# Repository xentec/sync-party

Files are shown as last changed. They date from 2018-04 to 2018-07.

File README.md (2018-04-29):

## Sync-Party

Synchrongesteurte RC-Autos.

### Kompileren

Zum Kompilieren des Projektes reicht es die `build.sh` auszuführen. Die fertigen Binaries liegen direkt im `bin`-Ordner.

### Settings

**Pololu Motor Controller**

The Pololu Motor Controller recieves a PWM signal via the RC1 pin from the arduino. If the PWM signal was generated with the following compare values (in register ORC2A) on the arduino the motor will speed up to the direction
	0x10 means full reverse speed
	0x30 means stop the motor
	0x90 means full forward speed

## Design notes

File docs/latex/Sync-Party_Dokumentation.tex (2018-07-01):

\RequirePackage{silence} % :-\
    \WarningFilter{scrreprt}{Usage of package `titlesec'}
    %\WarningFilter{scrreprt}{Activating an ugly workaround}
    \WarningFilter{titlesec}{Non standard sectioning command detected}
\documentclass[titlepage,paper=a4paper,fontsize=11pt, ngerman]{scrreprt}
\usepackage[left=2.5cm,right=2.5cm,top=2cm,bottom=2cm,includehead,includefoot]{geometry}

%********************************************************************
% Note: Make all your adjustments in here
%*******************************************************
\input{classicthesis-config}
% ********************************************************************
% GO!GO!GO! MOVE IT!
%*******************************************************
\begin{document}
\frenchspacing
\raggedbottom
\selectlanguage{ngerman} % american ngerman
%********************************************************************
% Frontmatter
%*******************************************************
\include{Gestaltung/Titlepage}
\include{Gestaltung/Contents}
%********************************************************************
% Mainmatter
%*******************************************************
\cleardoublepage
\pagestyle{scrheadings}
\pagenumbering{arabic}
\cleardoublepage
%\include{Kapitel/Einfuehrung}
\include{Anhang/Anhang}
\include{Anhang/literatur}
\end{document}
% ********************************************************************

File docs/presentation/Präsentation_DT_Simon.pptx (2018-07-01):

## Bitte beachten!

Auf den folgenden Seiten finden Sie Tipps zur Anwendung

## µController

- Hardware

  - Raspberry Pi 3 Model B
  - Arduino Uno Rev 3
  - Pololu Simple High-Power Motor Controller 18v15

## µController

- Hardware

  - Raspberry Pi 3 Model B
  - Arduino Uno Rev 3
  - Pololu Simple High-Power Motor Controller 18v15

## Controller

- Hardware

  - Playstation DUALSHOCK4 Wireless Controller

## Sensoren

- Hardware

  - Parallax INF PING))) Ultrasonic Distance Sensor
  - Logitech Webcam C300

## Aktuatoren

- Hardware

  - Modelcraft 4519 Servo
  - Brushed DC Motor (Chassis)

## Akkus

- Hardware

  - Power Bank
  - Nickel-Metall-Hybrid Akku

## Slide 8

- Pololu Motor Controller 18v15

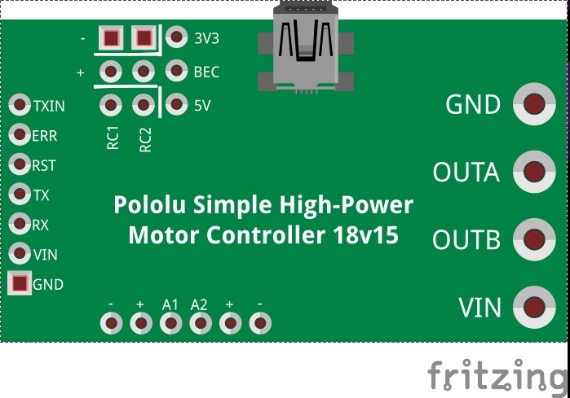
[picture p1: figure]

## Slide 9

- Pololu Motor Controller 18v15

- Kalibrierung: (RC1 Kanal)
Motor Stop: High Anteil 18.75%

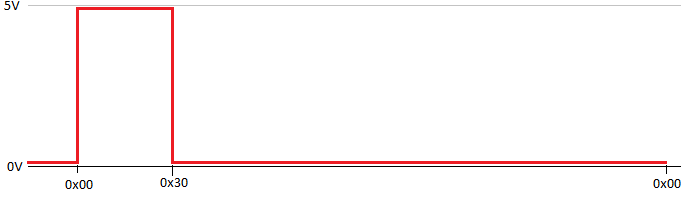
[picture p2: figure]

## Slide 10

- Pololu Motor Controller 18v15

- Kalibrierung: (RC1 Kanal)
Motor Full Forwards: High Anteil ~100%

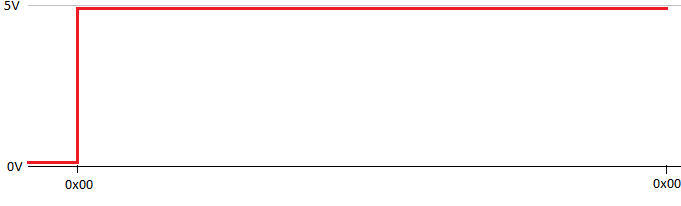
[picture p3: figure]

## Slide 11

- Pololu Motor Controller 18v15

- Kalibrierung: (RC1 Kanal)
Motor Full Backwards: High Anteil 6,25%

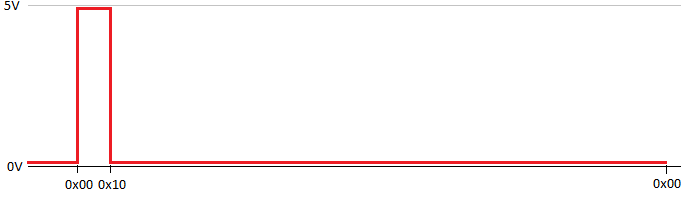
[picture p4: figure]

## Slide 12

- Modelcraft 4519 Servo

- Periodenlänge 2 ms

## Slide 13

- Parallax INF PING))) Ultrasonic Distance Sensor

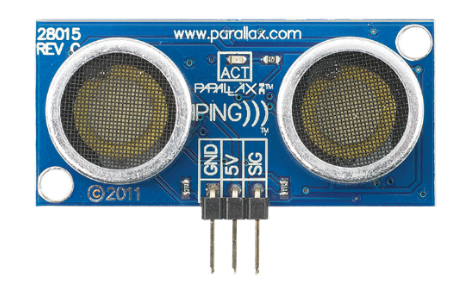
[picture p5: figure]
Ein Bild, das Tennis, Elektronik, Schläger enthält. Mit sehr hoher Zuverlässigkeit generierte Beschreibung
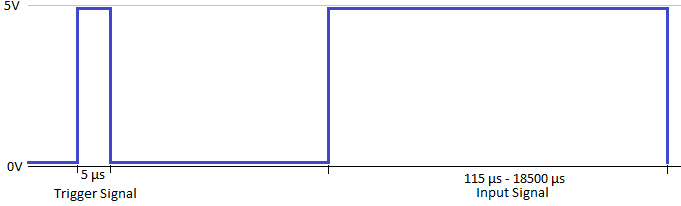
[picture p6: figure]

## Aufgaben

- Arduino Uno Rev 3

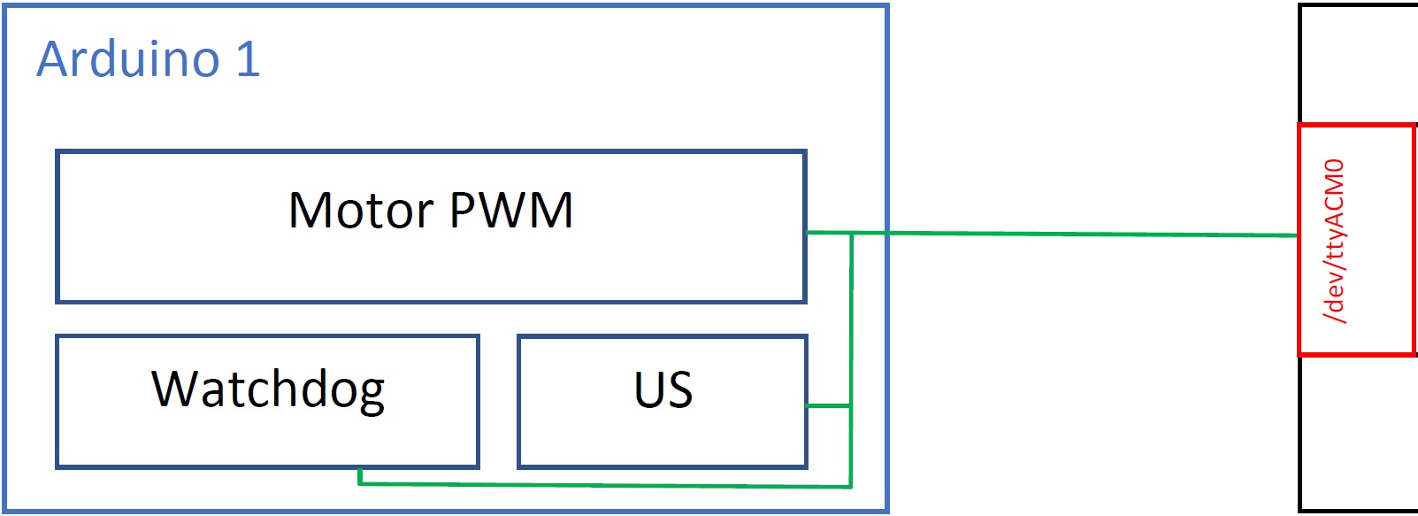
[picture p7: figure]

## PWM Signal

- Arduino Uno Rev 3

  - Ausgabe am Pin 11
  - Periodenlänge: 4 ms
  - Timer 2, FastPWM, Clear Pin 11 on Compare Match
  - Setzen der Compare Werte durch den Compare Interrupt

## Ultraschall

- Arduino Uno Rev 3

  - Ausgabe/Eingabe am Pin 7
  - Erzeugung des Trigger Signals
  - Messen des Input Signals
  - Umrechnung der Zeit in Distanz

## Watchdog

- Arduino Uno Rev 3

  - Überprüfen, ob das Programm auf den Raspberry Pi noch läuft
  - Periodisches Senden von Nachrichten über die serielle Schnittstelle
  - Warten bis Antwort kommt
  - Bei fehlender Antwort innerhalb 200 ms, Motor auf Stop schalten

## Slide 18

- Playstation DUALSHOCK4 Wireless Controller

- Verbindung über Bluetooth mit Master Raspberry Pi
- Steuerung der Geschwindigkeit über R2 (vorwärts) und L2 (rückwärts)
- Steuerung der Fahrtrichtung über den linken Joystick

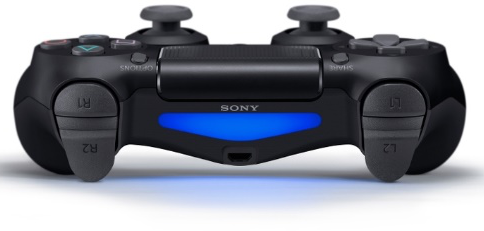
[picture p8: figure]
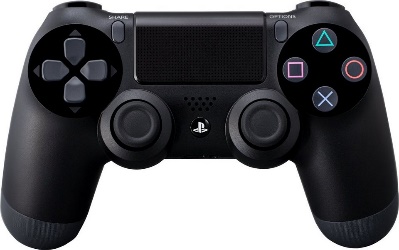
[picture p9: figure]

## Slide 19

- Schematischer Aufbau

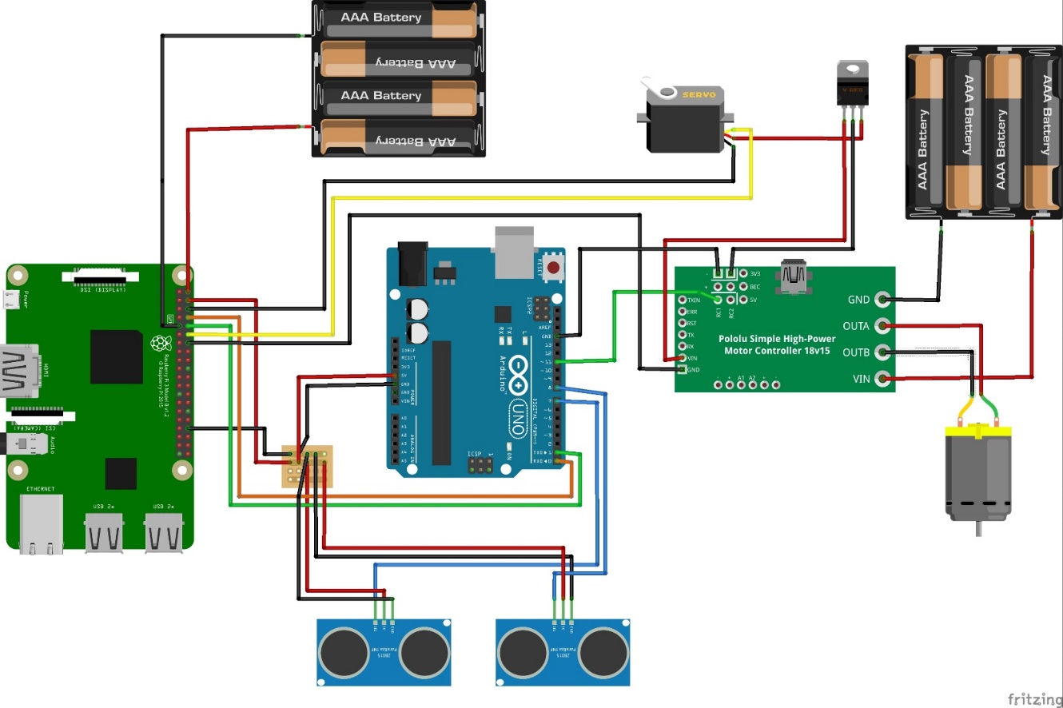
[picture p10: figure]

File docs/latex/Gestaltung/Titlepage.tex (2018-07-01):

%*******************************************************
%Gestaltung der Titelseite
%*******************************************************
\begin{titlepage}
	% if you want the titlepage to be centered, uncomment and fine-tune the line below (KOMA classes environment)
	
	\vspace{1cm}
	\begin{center}       
        \spacedallcaps{\small{\myUni}} \\
        \spacedallcaps{\small{\myFaculty}} \\ \vspace*{2\baselineskip}
		\Large     
        \begingroup
        	\spacedallcaps{\textbf{\myTitle}} \\ \vspace*{2\baselineskip}
            \textbf{\mySubtitle}
        \endgroup
        \large
        \vspace*{10\baselineskip}
		\begin{table}[h]
			\centering
			\begin{tabularx}{0.5\textwidth}{|X|X|}
			\hline 
			\textbf{Name} & \textbf{Matrikelnummer} \\
			\hline 
			Eichenseer, Johannes & 3106172 \\ 
			\hline 
			Hölzl, Simon & 3047424 \\ 
			\hline 
			Leher, Adrian & 3049303 \\ 
			\hline 
			Tran, Luu Ngoc & 3032963 \\ 
			\hline 
			Utz, Andrej & 3012095 \\ 
			\hline
			\end{tabularx}
		\end{table}
    	\begin{figure}[b]
    		\begin{center}
		    	\myTime, \myLocation
	    	\end{center}
    	\end{figure}
    \end{center}
\end{titlepage}

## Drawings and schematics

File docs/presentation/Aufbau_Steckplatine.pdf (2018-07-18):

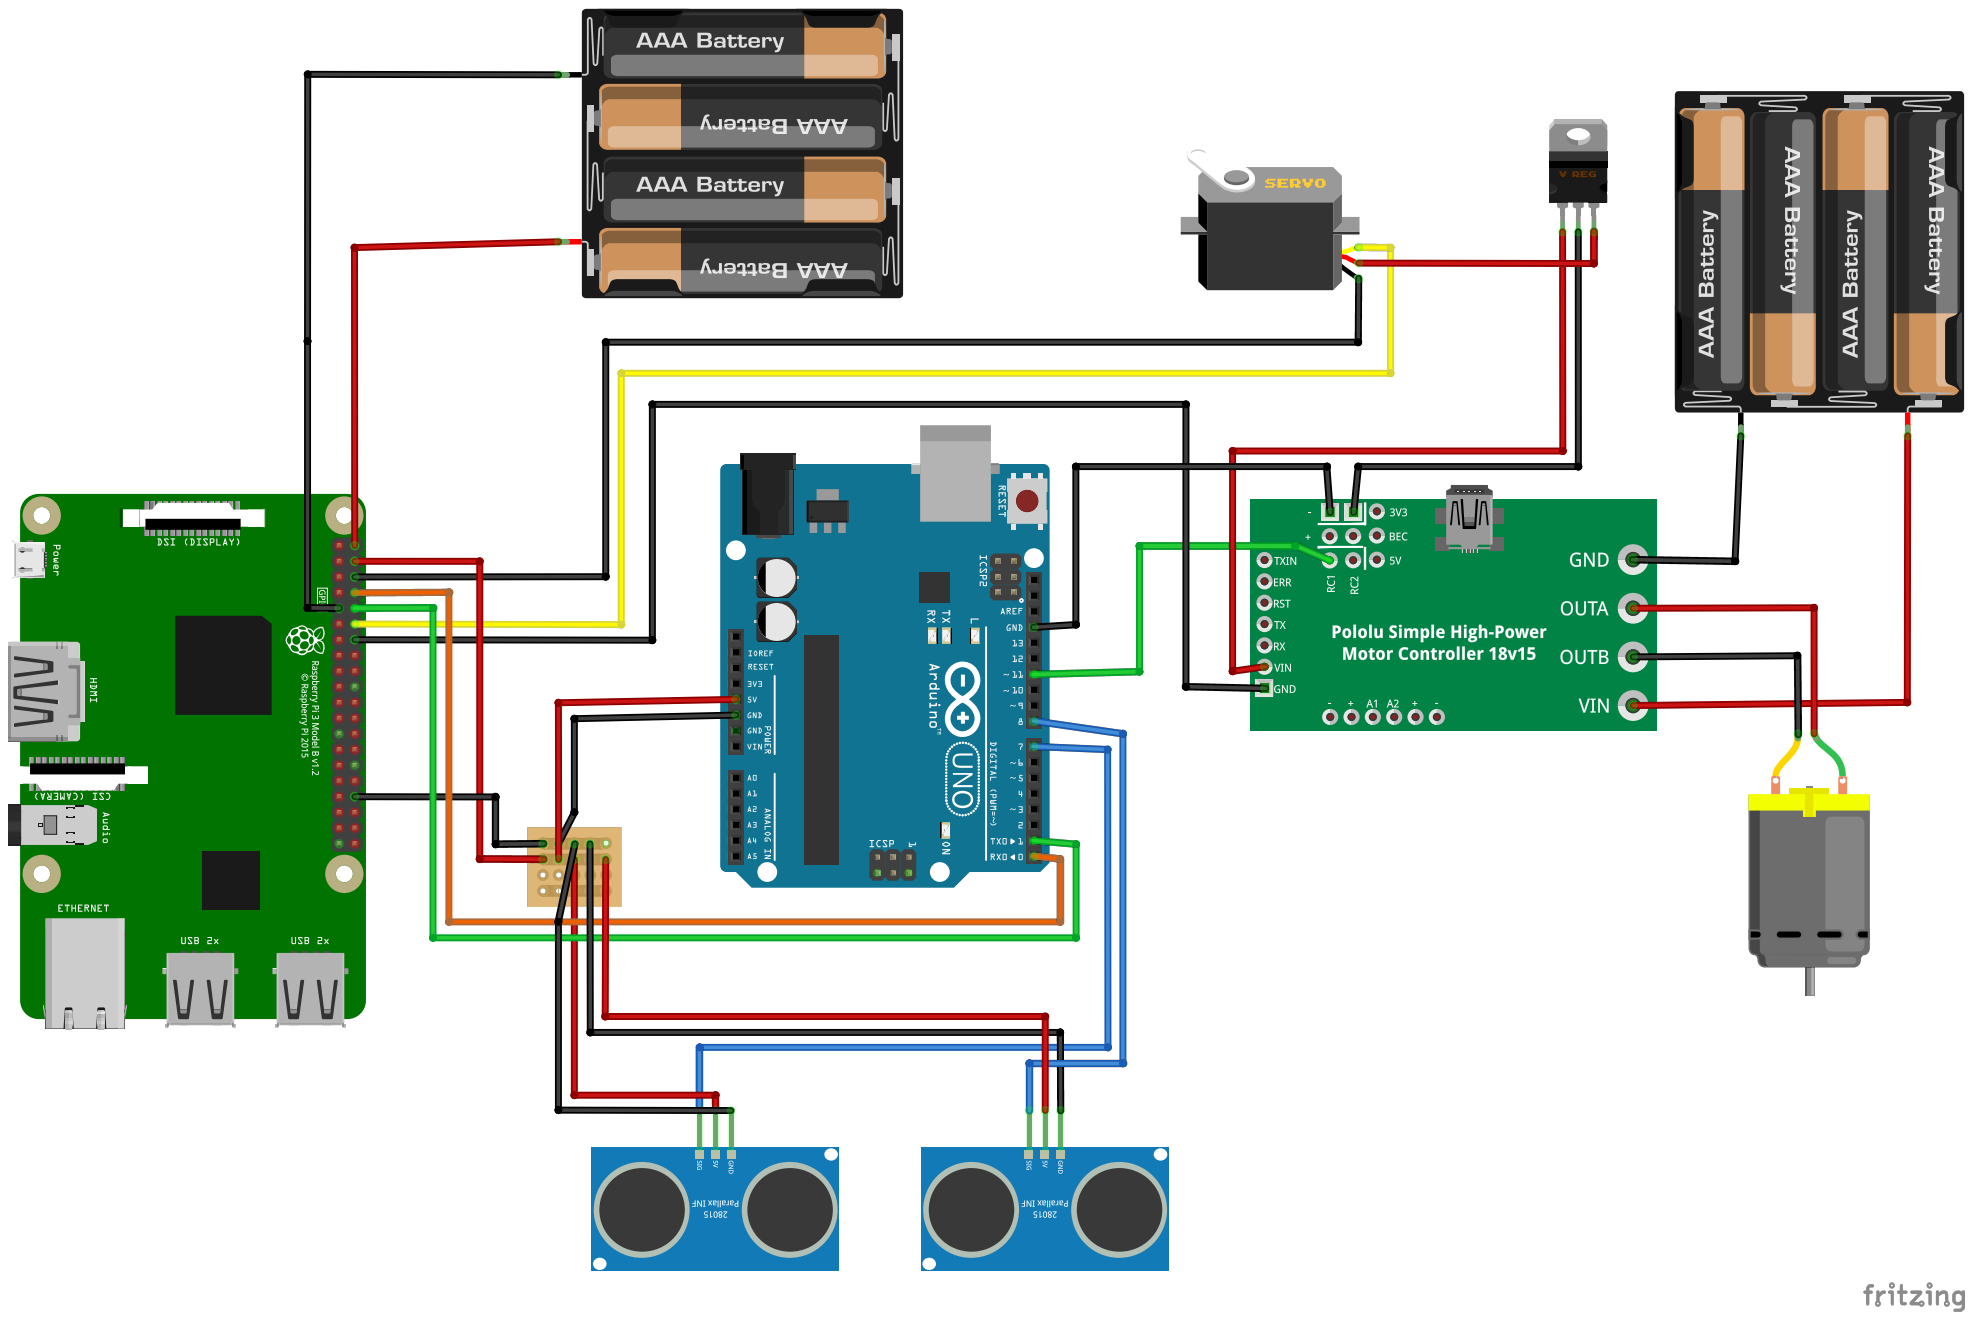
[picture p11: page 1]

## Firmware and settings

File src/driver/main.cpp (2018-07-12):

#ifndef __AVR_ATmega328P__
#define __AVR_ATmega328P__ // IDE helper
#endif

#include "proto-def.hpp"

#include <Arduino.h>
#include <avr/wdt.h>

#include <stdint.h>

#define FW_VERSION 4

#define MOTOR_PIN 11
#define PING_TIMEOUT_MS 200
#define PING_PIN 7
#define US_TIMEOUT_MIS 4000 // 18500


// UltraSonic
//############
uint8_t us_distance(uint8_t pin = PING_PIN)
{
	// start
	pinMode(pin, OUTPUT);
	digitalWrite(pin, LOW);
	delayMicroseconds(2);
	digitalWrite(pin, HIGH);
	delayMicroseconds(5);
	digitalWrite(pin, LOW);

	// wait for echo
	pinMode(pin, INPUT);
	uint32_t dur = pulseIn(pin, HIGH, US_TIMEOUT_MIS); // 18500

	return dur < 1450 ? dur / 5.8 : 255;
}

// Motor control
//###############
namespace motor
{
	byte ctrl = proto::Speed::STOP;

	void init()
	{
		pinMode(MOTOR_PIN, OUTPUT);
		pinMode(LED_BUILTIN, OUTPUT);

		// setup TIMER2
		//enable the compare interrupt, not needed at first time
		//TIMSK2 = (1<<OCIE2A);
		//set the compare register to the stop value
		OCR2A = 0x30;
		TCNT2 = 0x00;
		//set up the TIMER2 FastPWM Mode (WGM22-WGM20) and the clear ~OC2A on compare match, set OC2A at BOTTOM (COM2A1-COM2A0)
		TCCR2A = (1<<COM2A1) | (0<<COM2A0) | (1<<WGM21) | (1<<WGM20);
		//set the prescaler of TIMER2 to 256
		TCCR2B = (0<<WGM22) | (1<<CS22) | (1<<CS21) | (0<<CS20);
	}

	void set_speed(byte speed)
	{
		if(ctrl != speed)
		{
			ctrl = speed;
			//enable the compare interrupt
			TIMSK2 = (1<<OCIE2A);

			//change LED on the board when the motor is stopped
			digitalWrite(13, speed != proto::Speed::STOP ? HIGH : LOW);
		}
	}

	inline void stop()
	{
		set_speed(proto::Speed::STOP);
	}
};

ISR(TIMER2_COMPA_vect)
{
	//set the compare register to the new value
	OCR2A=motor::ctrl;
	//disable the compare interrupt
	TIMSK2 &= ~(1<<OCIE2A);
}

// Watchdog
//##########
struct Watchdog
{
	void reset(unsigned long new_timeout = PING_TIMEOUT_MS)
	{
		timeout = millis() + new_timeout;
	}
	bool check()
	{
		bool trigger = millis() > timeout;
		if(trigger)
		  timeout = -1; // never trigger until reset()
		return trigger;
	}
private:
	unsigned long timeout;
};

Watchdog wd;

// Serial communication
//######################
namespace comm
{

using namespace proto;

enum State
{
	SYNC, DATA
} state {};


void handle()
{
	// [<type><param>]

	byte type, data;
	int b;
	switch(state)
	{
	case State::SYNC:
		do {
			b = Serial.read();
			if(b == -1)
				return;
		} while(b != BYTE_SYNC);

		state = State::DATA;
	case State::DATA:
		if(uint32_t(Serial.available()) < PKT_SIZE - 1)
			return;

		state = State::SYNC;

		type = Serial.read();
		data = Serial.read();
		if(Serial.read() != BYTE_END)
			return;

		// jitter test
//		delay(random(20, 120));

		switch(Type(type))
		{
		case Type::PING:        break;
		case Type::VERSION:     data = FW_VERSION; break;
		case Type::MOTOR:       motor::set_speed(data); wd.reset(); break;
		case Type::ULTRA_SONIC: data = us_distance(data); break;
		case Type::ANALOG:      data = map(analogRead(data), 0, 1023, 0, 255); break;
		default:
			type |= ERR_BIT;
			data = Error::INVALID_ARG;
			break;
		}

		Serial.write(uint8_t(BYTE_SYNC));
		Serial.write(type);
		Serial.write(data);
		Serial.write(uint8_t(BYTE_END));
		break;
	default: break;
	}
}

}

// Main logic
//############
void setup()
{
	motor::init();
	wd.reset();
	Serial.begin(proto::BAUD);
	wdt_enable(WDTO_120MS);

	randomSeed(analogRead(0));
}

void loop()
{
	if(Serial.available())
		comm::handle();

	if(wd.check())
		motor::stop();

	wdt_reset();
}

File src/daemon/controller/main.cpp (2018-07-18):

#include "asio.hpp"
#include "def.hpp"
#include "echo.hpp"
#include "logger.hpp"
#include "net.hpp"
#include "opts.hpp"
#include "types.hpp"
#include "util.hpp"

#include "controller.hpp"

#include <boost/asio/signal_set.hpp>
#include <linux/input-event-codes.h>

/* master
 * controller -> mqtt
 * slave
 * mqtt -> driver, steering
*/

static const std::string NAME = "sp-ctrl";

struct {
	CommonOpts common;
	std::string dev_path = "/dev/input/js0";
	def::Scale speed = def::MOTOR_SCALE;
} conf;


int main(int argc, const char* argv[])
{
	slog::set_level(slog::level::trace);
	slog::set_pattern("[%Y-%m-%d %H:%M:%S %L] %n: %v");

	// custom default common values
	conf.common.name = NAME;

	// handle command line options
	argh::parser opts(argc, argv);
	conf.common.parse(opts);

	Controller::Type ctrl_type = Controller::Joystick;
	if(opts[{"-K", "--keyboard"}]) ctrl_type = Controller::Keyboard;
	opts({"-D", "--device"}, conf.dev_path) >> conf.dev_path;
	opts({"--spd-max"}, conf.speed.max) >> conf.speed.max;
	opts({"--spd-min"}, conf.speed.min) >> conf.speed.min;

	// let's go!
	auto logger = new_loggr("app");
	logger->info("sp-controller v0.1");

	io_context ioctx;

	logger->info("initialising controller...");
	Controller ctrl (ioctx, ctrl_type, conf.dev_path);

	logger->info("connecting with id {} to {}:{}", conf.common.name, conf.common.host, conf.common.port);
	MQTTClient cl (ioctx, conf.common.host, conf.common.port, conf.common.name);

	cl.set_will(def::MOTOR_SUB, "0");
	cl.connect();

	// helper for publishing MQTT messages
	auto forward = [&](const std::string& sub, i32 value_old, i32 value)
	{
		auto str = fmt::format_int(value).str();
		logger->debug("PUB: {}: {:3} -> {:3}", sub, value_old, str);
		cl.publish(sub, str);
	};

	// helpers for publishing respective messages of motor/steering
	auto motor = [&](i32 v){ on_change(v, [&](auto p, auto v){ forward(def::MOTOR_SUB, p, v); }); };
	auto steer = [&](i32 v){ on_change(v, [&](auto p, auto v){ forward(def::STEER_SUB, p, v); }); };

	// stop when controller went missing
	bool err = false;
	ctrl.on_err = [&](auto){ err = true, motor(0), steer(0); };

	// handle gamepad input events
	ctrl.on_axis = [&](u32, Controller::Axis num, i16 val)
	{
		// track axis state
		static std::unordered_map<Controller::Axis, i16> input_state_default
		{
			{ Controller::LS_H, 0 }, // left and right
			{ Controller::LT2, Controller::axis_min }, // backward
			{ Controller::RT2, Controller::axis_min }, // forward
		};
		static std::unordered_map<Controller::Axis, i16> input_state = input_state_default;

		if(err) // reset input state on error
			input_state = input_state_default;

		auto i = input_state.find(num);
		if(i == input_state.end())
			return;

		i->second = val;

		//logger->trace("on_axis: {:2} - {:6}", i->first, i->second);

		// calculate speed diff: forward - back
		i32 speed_input = input_state[Controller::RT2] - input_state[Controller::LT2];
		i32 speed_mapped =
		        map_dual(speed_input,
		                 Controller::axis_min * 2,  Controller::axis_max * 2,
		                 conf.speed.min, conf.speed.max);

		logger->trace("speed: {:6} -> {:4}", speed_input, speed_mapped);
		motor(speed_mapped);

		i32 steer_input = input_state[Controller::LS_H];
		i32 steer_mapped =
		        map<i32, i32>(steer_input,
		                      Controller::axis_min, Controller::axis_max,
		                      def::STEER_SCALE.min, def::STEER_SCALE.max);

		logger->trace("steer: {:6} -> {:4}", steer_input, steer_mapped);
		steer(steer_mapped);
	};

	// handle keyboard events
	ctrl.on_key = [&](u32, u32 code, Controller::KeyState val)
	{
		// track key state
		static std::unordered_map<u32, i32> input_state
		{
			{ KEY_W, 0 },
			{ KEY_S, 0 },
			{ KEY_A, 0 },
			{ KEY_D, 0 },
		};

		auto i = input_state.find(code);
		if(i == input_state.end())
			return;

		i->second = val > 0;

		logger->trace("on_key: {:2} - {:6}", i->first, i->second);

		// simple binary input: key down -> full speed
		motor(map_dual(input_state[KEY_W] - input_state[KEY_S], -1, 1, conf.speed.min, conf.speed.max));
		steer(def::STEER_SCALE.max * (input_state[KEY_D] - input_state[KEY_A]));
	};

	// in case the daemon needs to be found on a convoluted network
	std::shared_ptr<Echo> echo;
	if(conf.common.echo_broadcast)
		echo = std::make_shared<Echo>(ioctx, 31337, conf.common.name, std::chrono::seconds(10));

	// stop on system signal
	signal_set stop(ioctx, SIGINT, SIGTERM);
	stop.async_wait([&](auto, int) { ioctx.stop(); });

	// fire off the event loop
	logger->info("running...");
	ioctx.run();

	return 0;
}

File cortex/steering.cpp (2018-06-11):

#include "steering.hpp"

#include "util.hpp"

#include <fmt/format.h>
#include <experimental/filesystem>

namespace fs = std::experimental::filesystem;

enum {
	PERIOD =      20000000,

	DC_SERVO_MIN =  500000,
	DC_SERVO_MAX = 2500000,
	DC_PHY_MIN =   1200000,
	DC_PHY_MAX =   1800000,
};

static const fs::path path_ctl = "/sys/class/pwm/pwmchip0";
static const fs::path path_pwm = "/sys/class/pwm/pwmchip0/pwm0";

Steering::Steering(io_context &ioctx)
	: sd(ioctx)
{
	int fd;
	isz len;

	if(!fs::exists(path_pwm))
	{
		fd = open((path_ctl / "export").c_str(), O_WRONLY);
		if(0> fd)
			throw std::system_error(errno, std::system_category(), "path_ctl open");

		len = write(fd, "0\n", 2);
		if(0> len)
			throw std::system_error(errno, std::system_category(), "export");

		close(fd);
	}

	fd = open((path_pwm / "period").c_str(), O_WRONLY);
	if(0> fd)
		throw std::system_error(errno, std::system_category(), "period open");

	auto period = fmt::format("{}\n", PERIOD);
	len = write(fd, period.data(), period.size());
	if(0> len)
		throw std::system_error(errno, std::system_category(), "period write");
	close(fd);


	fd = open((path_pwm / "duty_cycle").c_str(), O_WRONLY);
	if(0> fd)
		throw std::system_error(errno, std::system_category(), "duty_cycle");

	sd.assign(fd);
	steer(0);

	fd = open((path_pwm / "enable").c_str(), O_WRONLY);
	if(0> fd)
		throw std::system_error(errno, std::system_category(), "enable");
	len = write(fd, "1\n", 2);
	close(fd);
}

Steering::~Steering()
{
	steer(i8(0));
	sd.close();

	// disable pwm0
	int fd = open((path_ctl / "unexport").c_str(), O_WRONLY);
	write(fd, "0\n", 2);
	close(fd);
}

void Steering::steer(i16 degree)
{
	steer_pwm(map<u32, i16>(degree, -9000, 9000, DC_PHY_MIN, DC_PHY_MAX));
}

void Steering::steer_pwm(u32 pwm)
{
	if(pwm > DC_PHY_MAX)
		pwm = DC_PHY_MAX;
	else if(pwm < DC_PHY_MIN)
		pwm = DC_PHY_MIN;

	sd.write_some(buffer(fmt::format("{}\n", pwm)));
}

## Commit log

2018-04-16 These files are used to control the pololu motor controller direct via the raspberry pi.
2018-04-18 In this folder is the code for the arduino.
2018-04-23 This file contains the code for the pwm generation on the arduino.
2018-04-27 Initial commit for all camera functions
2018-04-29 Restructure project
    - added arduino firmware
    - with drivers for
    - ultra sonic
    - motor
2018-04-29 (Re)add motor controls
    Those got lost somehow...
2018-04-30 driver: increase serial baud rate to 115200
2018-04-30 driver: fix missing pwm signal
    [main.cpp]
2018-05-07 cortex/contoller: don't skip input events
    [main.cpp]
2018-05-07 cortex/driver: implement command parser
2018-05-07 cortex: add sane driver controls
2018-05-07 Made some optimizations in the motor driver class.
2018-05-07 cortex: fix input fluctuations
    [main.cpp]
2018-05-07 cortex: add steering controls
2018-05-07 Der erste Entwurf des Aufbaus mit Fritzing.
    [Aufbau.fzz]
2018-05-07 cortex/steering: adapt pwm times for new servos
2018-05-07 cortex/driver: fix SEGFAULT in serial parser
2018-05-07 cortex: do some actual steering
2018-05-14 cortex/steering: fix DC values
    [steering.cpp]
2018-05-14 cortex/steering: fix dangling fd
    [steering.cpp]
2018-05-14 cortex/steering: create pwm0 only when missing
    [steering.cpp]
2018-05-14 cortex/driver: add watchdog feeder
2018-05-14 cortex/driver: fix timer runnning only once
2018-06-10 Separate controller component from cortex and also..
    - add mqtt infrastructure
    - cortex: fix some bugs in Driver
    - extern: update spdlog
    [main.cpp]
2018-06-11 cortex: fix wrong PWM range
    [steering.cpp]
2018-06-11 cortex: fix 'Invalid Option' error in Driver
2018-06-11 driver: format
2018-06-11 cortex: reduce Steering to a simple PWM controller
2018-06-11 controller: fix non-changing values
    [main.cpp]
2018-06-11 cortex: fix mapping on RPi
    [main.cpp]
2018-06-11 driver: enable hardware watchdog
2018-06-11 controller: fix input directions
    [main.cpp]
2018-06-11 cortex: reduce motor speed
2018-06-11 driver: add analog reading
2018-06-12 driver: add helper define for IDEs
    Allows semantic parsing
2018-06-13 Update Fritzing Aufbau
    [Aufbau.fzz]
2018-06-13 Clean up
    [Aufbau.fzz]
2018-06-18 cortex: propagate errors from driver
2018-06-18 driver: add ANALOG & VERSION functinality
2018-06-18 driver: fix analog reading
    [main.cpp]
2018-06-21 cortex: do not reset Driver on close
2018-06-21 Extract Driver protocol definitions
2018-06-21 driver: update protocol: use msb bit for errors
    [main.cpp]
2018-06-21 cortex: implement timeouts & retries for Driver
2018-06-25 driver: output distance samples in cm
2018-06-28 controller: fix input axis (for the last time)
    [main.cpp]
2018-06-28 cortex: fix motor mapping
    [main.cpp]
2018-07-01 Improve Cortex-Driver protocol once more
2018-07-01 This files are for the presentation and documentation
    [Aufbau.fzz]
2018-07-02 cortex: add recur_timer for easier timer setup
2018-07-02 cortex: added speed and steering correction
    [main.cpp]
2018-07-02 camera: start refactoring
2018-07-02 Update Cam
    Switching to std::threads, return var to atomic
2018-07-02 add atomic vars & cam timer
2018-07-02 cortex: make camera work again
2018-07-02 main: better error handling for camera init
    [main.cpp]
2018-07-02 controller: fix garbage in forwarded strings
    [main.cpp]
2018-07-02 cortex: consider updating speed state in steer correction
    [main.cpp]
2018-07-02 fixed camera tracker restart
2018-07-02 cortex: remove usonic pin switch (debug code)
2018-07-02 cortex: limit motor speed and enforce it
2018-07-04 improved camera error handling
    [main.cpp]
2018-07-04 include camera into adjust
2018-07-04 fix init for variable
    [main.cpp]
2018-07-04 third time fix init
    [main.cpp]
2018-07-05 Add wifi-ap helper script
    Start `./wifi-ap.sh` as root for instant hot-spot.
    Switch back to local wifi with `./wifi-ap.sh off`
2018-07-05 Consolidate recur_timer into common as Timer
2018-07-05 controller: recover device connection when possible
2018-07-05 speed + steer limit
2018-07-05 Reduce network load by scaling speed/steering down even more
2018-07-05 Fix build without explicit fmtlib
    [main.cpp, pwm.cpp]
2018-07-05 cortex: consolidate drive/steer fn
2018-07-05 cortex: fix static gap value
    [main.cpp]
2018-07-05 cortex: update steering and speed only on changes
2018-07-05 cortex: fix stupid bugs and clamp PWM
    [main.cpp]
2018-07-08 cortex: switch to degrees as default steering value instead of PWM
2018-07-08 controller: add options to specify input type and device path
2018-07-08 cortex: shift motor speed scale so that 0 means STOP
2018-07-08 controller: stop Cortex on crash via mqtt will
    [main.cpp]
2018-07-08 cortex: add logger to PWM
2018-07-08 cortex/adjust: fix speed degradation after steering
    [main.cpp]
2018-07-08 cortex: add option for camera fetch interval
2018-07-09 cortex/adjust: fix speed calculations
    math at 3 am is really... REALLY hard...
    but not impossible \o/
    [main.cpp]
2018-07-09 cortex: limit motor speed in Driver
2018-07-09 cortex/adjust: fix steering degradation
2018-07-09 cortex/adjust: decrease cam correction
    [main.cpp]
2018-07-09 driver: return usonic in mm
2018-07-09 driver: put BAUD in one place
2018-07-09 Bugfix on camera tracker
2018-07-09 cortex: fix residing gap factor
    [main.cpp]
2018-07-09 cortex: increase motor speed a little
2018-07-18 Die Dokumentation wird auf Overleaf.com erstellt
